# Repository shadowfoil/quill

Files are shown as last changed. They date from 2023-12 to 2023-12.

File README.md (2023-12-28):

# Quill Macropad

Render_Main Camera 10_FullQuality_079

The "Quill" is a 3 key, 2 encoder hot-swappable macropad shield utilizing an RP2040-Zero MCU board as a controller.

vial-qmk firmware is preconfigured and ready to compile.

All PCB/Schematic files are available.

3D CAD Drawings are also available for the PCB as well as two cases that can be printed, machined, or laser cut from various materials.

Enjoy!

### Recommended PCB Specs
 - Thickness: 1.6mm PCB
 - Finish: ENIG (HASL works fine as well)
 - Soldermask: White (personal preference)
 - Silkscreen: Black (personal preference)

### PCB 







### Schematic



### Photos








### More Renders

Render_Main Camera 10_FullQuality_080

Render_Main Camera 10_FullQuality_081

Full Plate Style Case Exploded View
Render_Main Camera 10_FullQuality_085

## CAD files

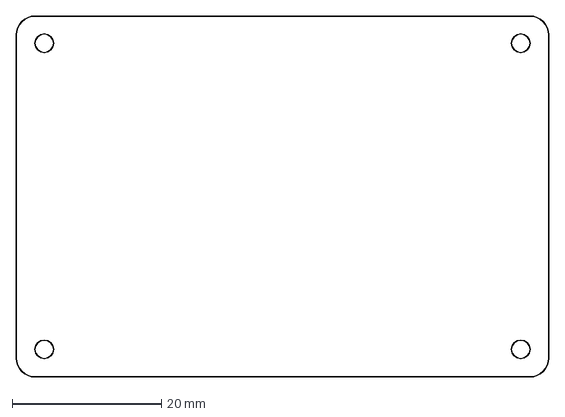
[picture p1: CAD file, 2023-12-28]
3DCAD/DXF/QuillBotCut.dxf
71.3 x 48.3 mm

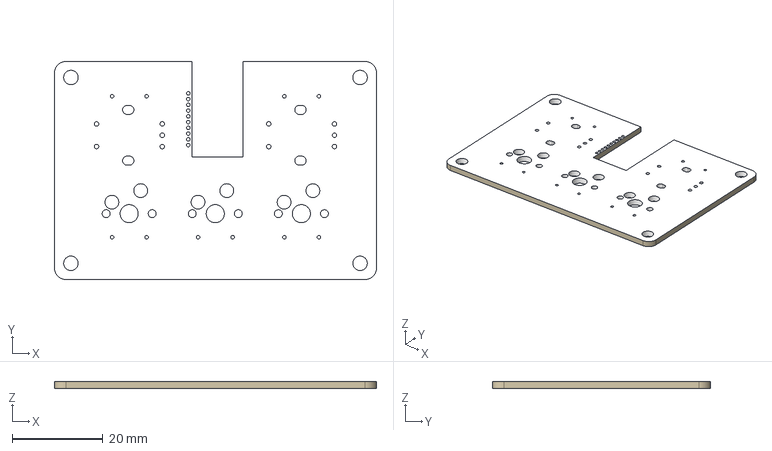
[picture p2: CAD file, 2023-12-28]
3DCAD/STEP/QuillPCB.step
71.1 x 48.1 x 1.60 mm

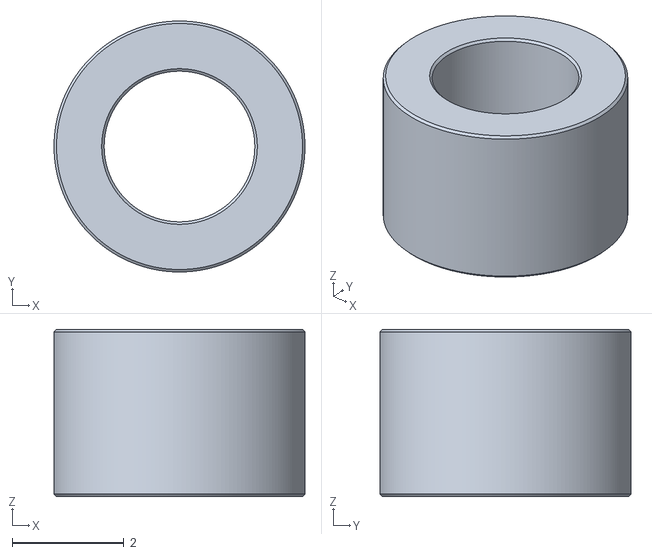
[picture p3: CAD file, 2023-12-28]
3DCAD/STL/PlateCase/3mmUnthreadedSpacer.stl
4.50 x 4.50 x 3.00

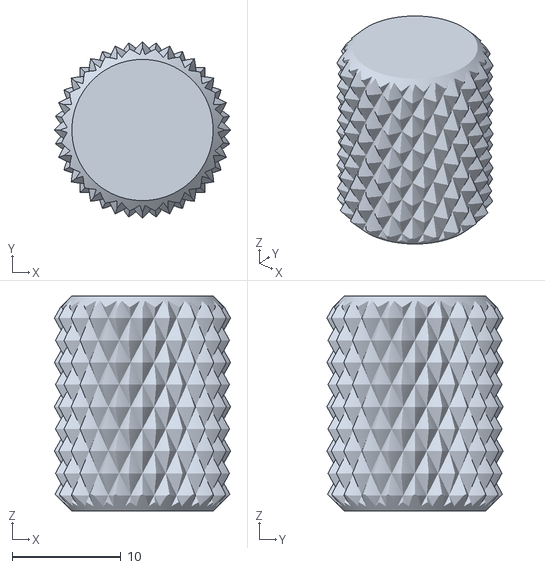
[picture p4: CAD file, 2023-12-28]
3DCAD/STL/PrintableKnob.stl
16.2 x 16.2 x 19.8

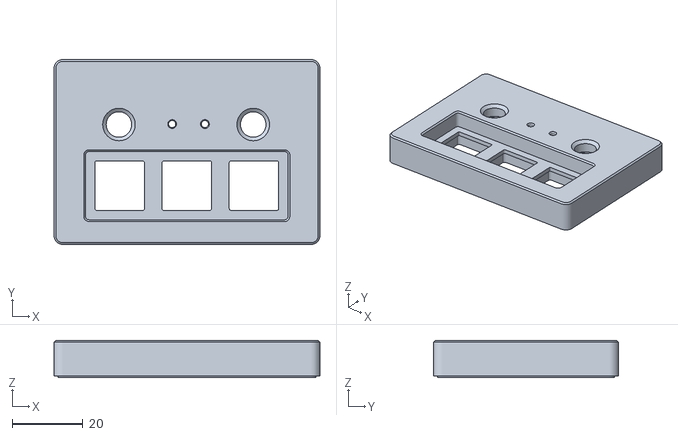
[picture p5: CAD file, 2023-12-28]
3DCAD/STL/ShellCase/ShellTop.stl
75.3 x 52.3 x 10.6

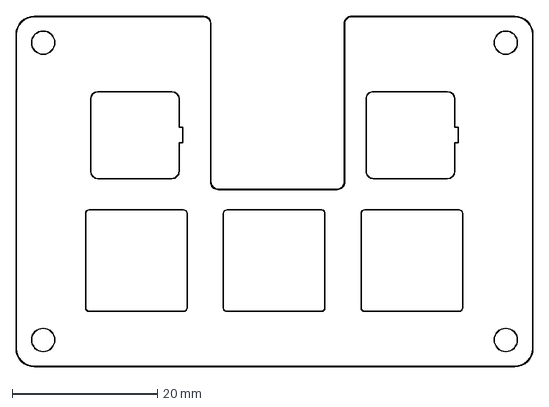
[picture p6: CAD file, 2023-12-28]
3DCAD/DXF/QuillTopCut.dxf
71.3 x 48.3 mm

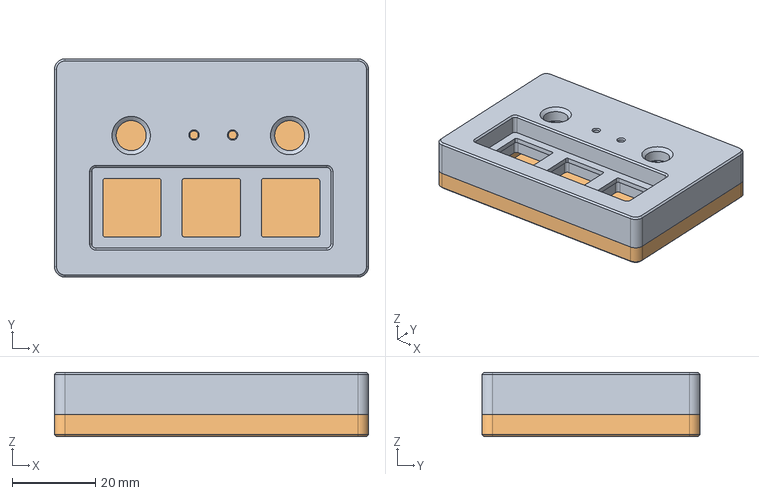
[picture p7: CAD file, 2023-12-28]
3DCAD/STEP/ShellCase.step
75.3 x 52.3 x 15.4 mm
ShellTop
ShellBottom

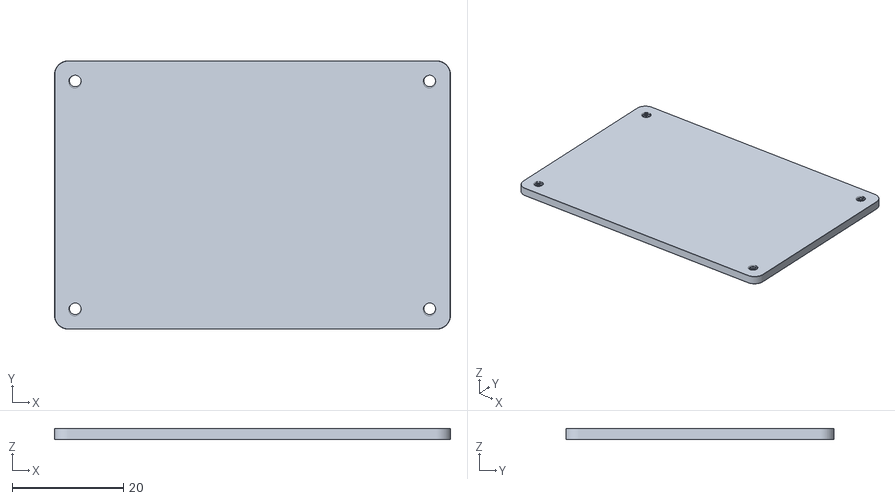
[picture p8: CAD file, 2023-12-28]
3DCAD/STL/PlateCase/BotPlate.stl
71.3 x 48.3 x 2.00

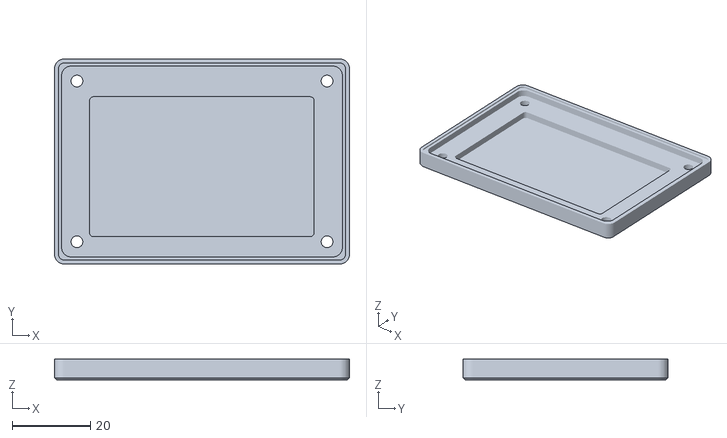
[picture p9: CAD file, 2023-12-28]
3DCAD/STL/ShellCase/ShellBottom.stl
75.3 x 52.3 x 5.25

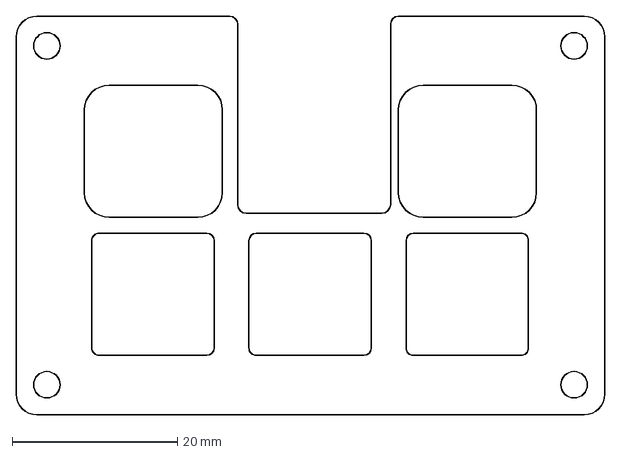
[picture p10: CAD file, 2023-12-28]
3DCAD/DXF/QuillMidCut.dxf
71.2 x 48.2 mm

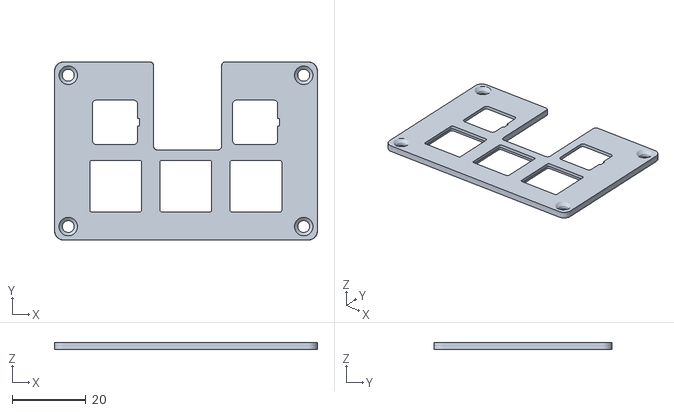
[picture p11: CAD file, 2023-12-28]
3DCAD/STL/PlateCase/MergedTopPlate.stl
71.3 x 48.3 x 2.00

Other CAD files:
PCB/Quill.step

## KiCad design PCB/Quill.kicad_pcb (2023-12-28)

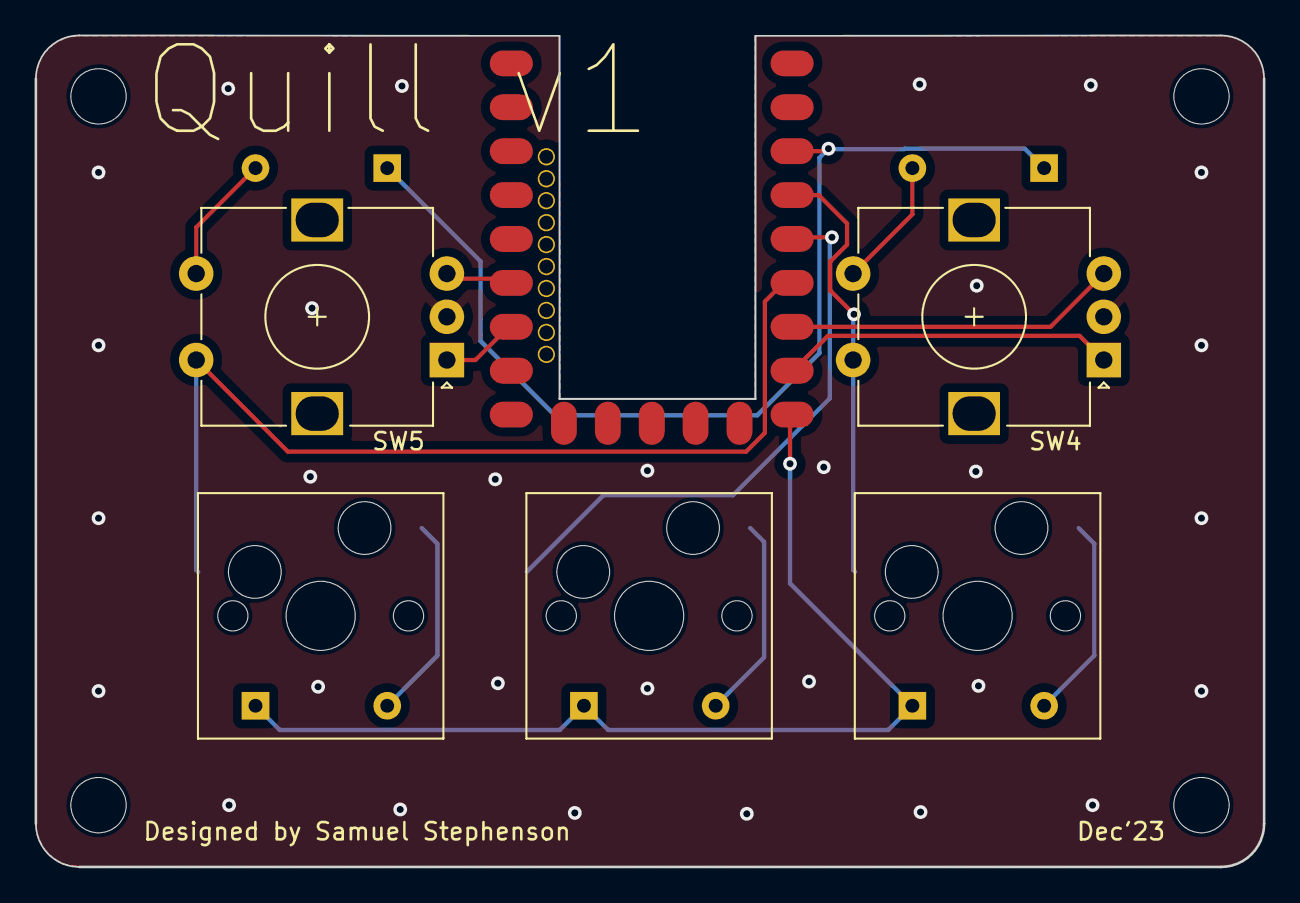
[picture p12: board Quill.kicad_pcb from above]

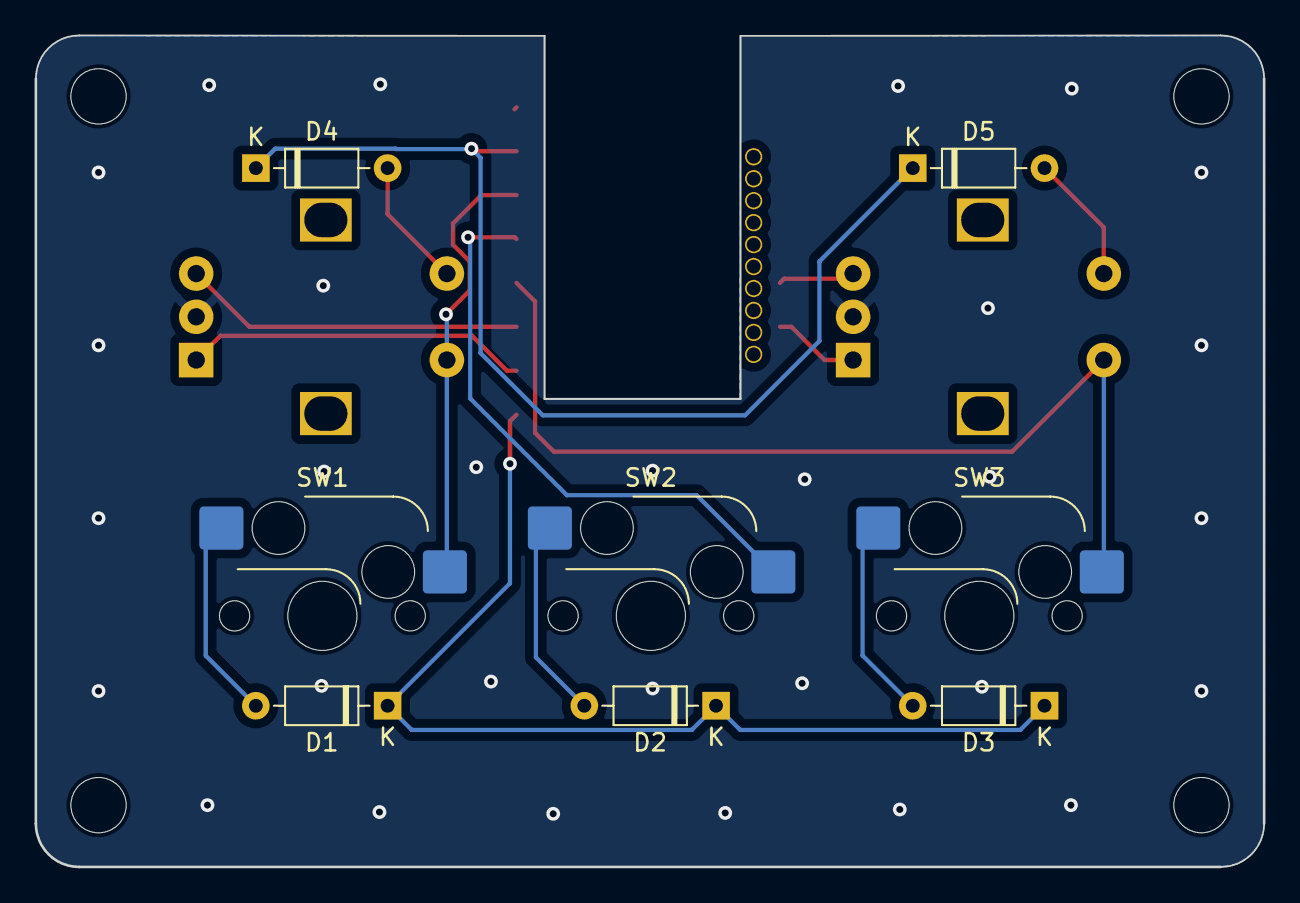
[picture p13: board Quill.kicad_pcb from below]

Board: 2 copper layers, 71.1 x 48.1 mm, 15 parts (8 on the bottom side), 15 nets.

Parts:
D1, D2, D3, D4, D5: 1N4148; D_DO-35_SOD27_P7.62mm_Horizontal
MH1, MH2, MH3, MH4: MountingHole_3.2mm_M3
SW1, SW2, SW3: SW_SPST; SW_Hotswap_Kailh_MX_1.00u
SW4, SW5: RotaryEncoder_Switch; RotaryEncoder_Alps_EC12E-Switch_Vertical_H20mm
U1: rp2040-zero-smd-pads

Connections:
/SW1: D1.2 (A), SW1.2 (B)
Col1: SW1.1 (A), SW4.S1, U1.3 (GP3)
Col2: SW2.1 (A), U1.4 (GP4)
Col3: SW3.1 (A), SW5.S1, U1.5 (GP5)
ENC1A: SW4.A, U1.7 (GP7)
ENC1B: SW4.B, U1.6 (GP6)
ENC2A: SW5.A, U1.17 (GP17), U1.26 (GP26)
ENC2B: SW5.B, U1.18 (GP18), U1.27 (GP27)
GND: SW4.C, SW5.C, U1.22 (GP22)
unnamed: D2.2 (A), SW2.2 (B)
unnamed: D3.2 (A), SW3.2 (B)
unnamed: D4.2 (A), SW4.S2
unnamed: D5.2 (A), SW5.S2
Row1: D1.1 (K), D2.1 (K), D3.1 (K), U1.8 (GP8)
Row2: D4.1 (K), D5.1 (K), U1.2 (GP2)

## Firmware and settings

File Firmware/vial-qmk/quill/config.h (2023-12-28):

/* Copyright 2023 shadowfoil

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
You should have received a copy of the GNU General Public License
along with this program.  If not, see <http://www.gnu.org/licenses/>. */

#pragma once

#define DEBUG_MATRIX_SCAN_RATE

//#include "config_common.h"

/* USB Device descriptor parameter */
/*
#define VENDOR_ID       0x6D6A
#define PRODUCT_ID      0x5965
#define DEVICE_VER      0x0001
#define MANUFACTURER    MAJIN
#define PRODUCT         DRIFT
*/

/* Key Matrix Size */
#define MATRIX_COLS 3
#define MATRIX_ROWS 2
#define DIODE_DIRECTION COL2ROW

/* Wiring of Columns and Rows */
#define MATRIX_ROW_PINS { GP2, GP8 }		// 2 Pins
#define MATRIX_COL_PINS { GP5, GP4, GP3 }	// 3 Pins

/* -==== Encoder Pins ====- */
#define ENCODERS_PAD_A { GP26, GP7 }
#define ENCODERS_PAD_B { GP27, GP6 }

// #define ENCODER_DIRECTION_FLIP
//#define ENCODER_RESOLUTION 4
//#define ENCODER_RESOLUTION 2
#define ENCODER_DEFAULT_POS 0x3

/* LED Settings */
// #define WS2812_DI_PIN GP16
#define NOP_FUDGE 0.4
#define WS2812_BYTE_ORDER WS2812_BYTE_ORDER_RGB
#define RGBLIGHT_EFFECT_ALTERNATING
#define RGBLIGHT_EFFECT_BREATHING
#define RGBLIGHT_EFFECT_CHRISTMAS
#define RGBLIGHT_EFFECT_RAINBOW_MOOD
#define RGBLIGHT_EFFECT_RGB_TEST
// #define RGBLED_NUM 1 // Number of LEDs
// #define DRIVER_LED_TOTAL RGBLED_NUM

/* Split Definitions */
// #define SPLIT_LAYER_STATE_ENABLE
// #define SPLIT_LED_STATE_ENABLE
// #define SPLIT_MODS_ENABLE

/* Serial settings */
#define USE_SERIAL
#define SOFT_SERIAL_PIN GP0 //TX in Schematic
#define SERIAL_USE_MULTI_TRANSACTION
/* Communication between Sides: The PIO driver */
// The PIO subsystem is a Raspberry Pi RP2040 specific implementation,
// using the integrated PIO peripheral and is therefore only available on this MCU.
// Because of the flexible nature of the PIO peripherals, any GPIO pin can be used as a TX or RX pin.
#define SERIAL_PIO_USE_PIO1
// Half-duplex and Full-duplex operation is fully supported.
// The Half-duplex operation mode uses the built-in pull-ups and GPIO manipulation on the RP2040
// to drive the line high by default. An external pull-up is therefore not necessary.

/* External VBUS via 5V through diode to GP29 */
// for rp2040 | When USB_VBUS_PIN is not defined, SPLIT_USB_DETECT is used.
// #undef SPLIT_USB_DETECT
// #define USB_VBUS_PIN GP29

/* Fix for the RP2040-ZERO Wake up bug - you can't enter BIOS with these enabled tho */
// use this instead of VBUS hack above if lazy to use diodes and switches on each side
//#define SPLIT_USB_TIMEOUT 10000
//#define SPLIT_USB_TIMEOUT_POLL 10

/* Use 1000hz polling */
#define USB_POLLING_INTERVAL_MS 1

/* OLED Definitions */
// #define I2C_DRIVER I2CD0
// #define I2C1_SDA_PIN GP12
// #define I2C1_SCL_PIN GP13
// #define OLED_DISPLAY_128X64

/* Audio Definitions */
// #ifdef AUDIO_ENABLE
// #	define AUDIO_PIN GP1
// #	define AUDIO_PWM_DRIVER PWMD0
// #	define AUDIO_PWM_CHANNEL RP2040_PWM_CHANNEL_B
// #endif

//#define NO_ACTION_MACRO
//#define NO_ACTION_FUNCTION

#define DEBOUNCE 5

#define RP2040_BOOTLOADER_DOUBLE_TAP_RESET
#define RP2040_BOOTLOADER_DOUBLE_TAP_RESET_TIMEOUT 500U

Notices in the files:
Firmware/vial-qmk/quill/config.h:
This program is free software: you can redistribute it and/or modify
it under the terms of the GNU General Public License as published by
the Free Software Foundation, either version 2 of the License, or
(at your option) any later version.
